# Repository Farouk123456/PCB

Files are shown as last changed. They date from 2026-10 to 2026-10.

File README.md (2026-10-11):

# Submission for Halflife's Week 1 PCB design

## CPULess Multiplexed LED Matrix 

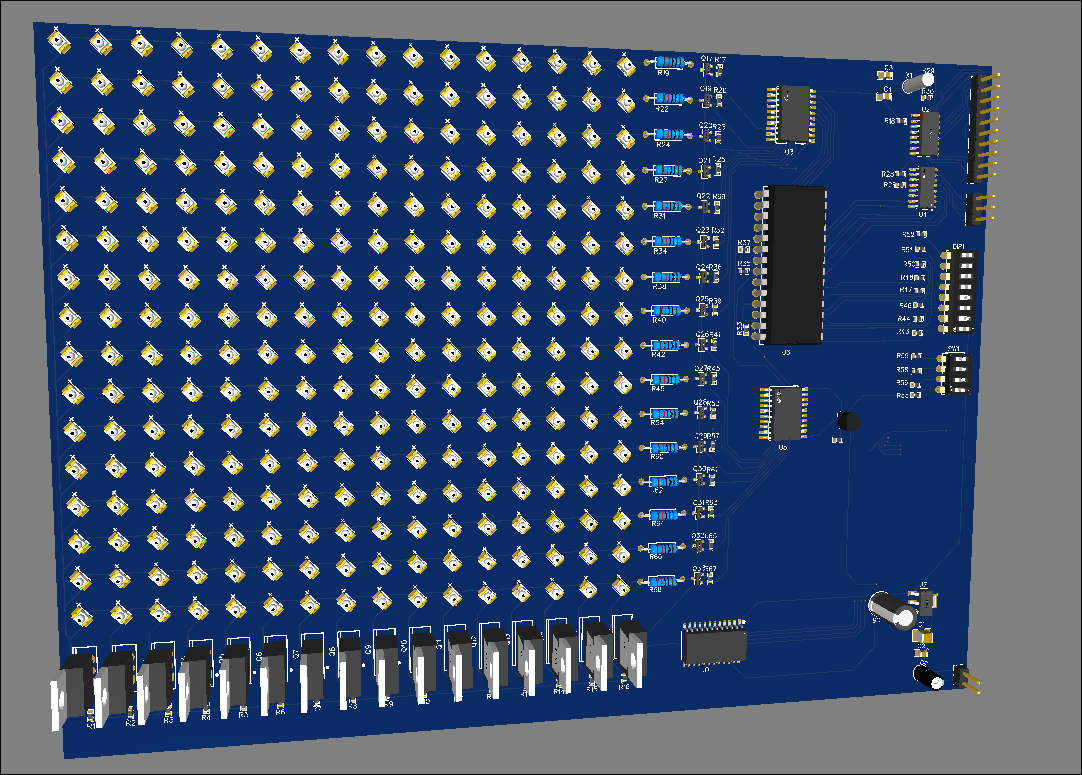
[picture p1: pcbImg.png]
PCB Model Image


This is a 16x16 LED display/matrix that's driven only by logic gates and an AT28C256 EEPROM to store an image, meaning there's no CPU or microcontroller that's controlling the LEDs.

I was motivated to make this to challenge myself to see what it would take and if I could actually design something complex that works, hopefully!

When the board powers on, a crystal oscillator is used alongside a 74HC4060 IC counter to generate a clock signal and to (in the future) automatically cycle between images using the counter that is its intended purpose.

That clock signal powers a 74HC590 8-bit counter that sets which row (or column, depending on how you want to look at it) is now to be displayed
A 74HC4514 demultiplexer IC actually enforces what the counter sets and powers on one row at a time (the multiplexing part). 

Simultaneously the counter value gets passed to the EEPROM as an address.
The EEPROM then returns the values of half a column of LEDs as an 8-bit value.
The value travels through one of two buffer ICs and through some transistors to power on the selected LEDs.

On the next clock cycle the other half is displayed by the EEPROM

Then a new row is addressed until it reaches row 16, where the counter resets and the process happens all over again

The 12 DIP switches allow me to select one of 4096 possible images to be displayed on the matrix
(It's noteworthy to say that my implementation only allows the LEDs to be either on or off.)

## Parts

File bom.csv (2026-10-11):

Index | LCSC# | MPN | Manufacturer | Package | Customer # | Description | RoHS | Quantity | MOQ | Multiple | Unit Price($) | Extended Price($) | Product Link
1 | C3356784 | MFR-12FTF52-10K | YAGEO | Through Hole,D1.9xL3.4mm |  | 10kΩ 167mW Metal Film Resistor ±100ppm/℃ ±1% Through Hole,D1.9xL3.4mm Through Hole Resistors RoHS | yes | 100 | 50 | 50 | 0.0113 | 1.13 | https://www.lcsc.com/product-detail/C3356784.html
2 | C52121519 | HG74HC595N | HGSEMI | DIP-16 |  | 3.2V~5.5V 35mA 100ns@5V,50pF Serial-to-Parallel DIP-16 Shift Registers | yes | 5 | 5 | 5 | 0.1336 | 0.67 | https://www.lcsc.com/product-detail/C52121519.html
3 | C907564 | CD02K032768ACNBAEAE | TKD | DT-38 |  | 12.5pF ±10ppm DT-38 Crystals | yes | 10 | 10 | 10 | 0.0602 | 0.60 | https://www.lcsc.com/product-detail/C907564.html
4 | C544820 | LM3940IMPX-3.3/NOPB | TI | SOT-223-4 |  | Linear Voltage Regulator IC Positive Fixed 1 Output 1A SOT-223-4 | yes | 1 | 1 | 1 | 1.5028 | 1.50 | https://www.lcsc.com/product-detail/C544820.html
5 | C1348752 | AT28C256-15PU | MICROCHIP | PDIP-28 |  | 256Kbit Parallel Port (Parallel) PDIP-28 Memory RoHS | yes | 1 | 1 | 1 | 19.4572 | 19.46 | https://www.lcsc.com/product-detail/C1348752.html
6 | C2652997 | SN74HC590ADR | TI | SOIC-16 |  | Rising Edge 1 24MHz SOIC-16 Counters, Dividers RoHS | yes | 1 | 1 | 1 | 0.8522 | 0.85 | https://www.lcsc.com/product-detail/C2652997.html
7 | C548810 | 74LVC541AD-Q100J | Nexperia | SO-20-300mil |  | Schmitt trigger 1.65V~3.6V 8 1 2.9ns@3.3V,50pF SO-20-300mil Buffers, Drivers, Receivers, Transceivers RoHS | yes | 2 | 1 | 1 | 1.0705 | 2.14 | https://www.lcsc.com/product-detail/C548810.html
8 | C134017 | CD74HC4060M96 | TI | SOIC-16 |  | Falling Edge 1 35MHz SOIC-16 Counters, Dividers RoHS | yes | 1 | 1 | 1 | 0.4685 | 0.47 | https://www.lcsc.com/product-detail/C134017.html
9 | C50202050 | XL74HC4514D | XINLUDA | SOP-24 |  | 4/16 2V~6V 80uA 49ns@6.0V,50pF SOP-24 Signal Switches, Multiplexers, Decoders | yes | 5 | 5 | 5 | 0.3097 | 1.55 | https://www.lcsc.com/product-detail/C50202050.html
10 | C99987 | EI-04 | Diptronics | Through Hole,P=2.54mm |  | Dip Switch SPST 4 Position Slide, Rocked | yes | 1 | 1 | 1 | 0.5224 | 0.52 | https://www.lcsc.com/product-detail/C99987.html
11 | C20611863 | MF0204FTE52-2K2 | YAGEO | Through Hole,D1.9xL3.4mm |  | 2.2kΩ 400mW Metal Film Resistor ±50ppm/℃ ±1% Through Hole,D1.9xL3.4mm Through Hole Resistors | yes | 50 | 50 | 50 | 0.0115 | 0.58 | https://www.lcsc.com/product-detail/C20611863.html
12 | C3000673 | FRC2512F1004TS | FOJAN | 2512 |  | 1MΩ ±1% 1W 2512 Thick Film Resistor | yes | 20 | 20 | 20 | 0.0324 | 0.65 | https://www.lcsc.com/product-detail/C3000673.html
13 | C119285 | MF1/4W-15Ω±1% T | CCO(Chian Chia Elec) | Through Hole,D2.3xL6.5mm |  | 15Ω 250mW 250V Metal Film Resistor ±100ppm/℃ ±1% Through Hole,D2.3xL6.5mm Through Hole Resistors RoHS | yes | 50 | 50 | 50 | 0.0109 | 0.55 | https://www.lcsc.com/product-detail/C119285.html
14 | C49270298 | CSA0805C0G103J500MT | HRE | 0805 |  | 10nF C0G ±5% 50V 0805 Ceramic Capacitors | yes | 20 | 20 | 20 | 0.0312 | 0.62 | https://www.lcsc.com/product-detail/C49270298.html
15 | C2910414 | 2N7000-TA | JSCJ | TO-92 |  | N-Channel 60V 0.2A 0.625W Through Hole TO-92 | yes | 20 | 20 | 20 | 0.0451 | 0.90 | https://www.lcsc.com/product-detail/C2910414.html
16 | C21713833 | AO3401CI-ES | ElecSuper | SOT-23 |  | P-Channel 20V 2.3A 1.4W Surface Mount SOT-23 | yes | 50 | 50 | 50 | 0.0191 | 0.96 | https://www.lcsc.com/product-detail/C21713833.html
17 | C54839582 | IRLZ44NPBF-MNS | Minos | TO-220 |  | 100W 60V 50A 15mΩ@10V 1 N-channel N-Channel TO-220 Single FETs, MOSFETs | yes | 20 | 5 | 5 | 0.3046 | 6.09 | https://www.lcsc.com/product-detail/C54839582.html
18 | C131211 | 42-21A/GHC-YX1Y2N/1T | EVERLIGHT | SMD,3.2x2.4mm |  | Emerald Green 518nm LED Indication - Discrete SMD,2.4x3.2mm | yes | 260 | 10 | 10 | 0.0501 | 13.03 | https://www.lcsc.com/product-detail/C131211.html
19 | C124375 | B-2100S02P-A110 | Ckmtw | Through Hole,P=2.54mm |  | Pin Header 2 Position 2.54mm Pitch Single Row Through Hole -40℃~+105℃ | yes | 20 | 20 | 20 | 0.0300 | 0.60 | https://www.lcsc.com/product-detail/C124375.html
20 | C54557117 | 5557WRF-1X3P(HDGC4201WR-F-1X3P) | HDGC | Through Hole,Right Angle,P=4.2mm |  | Right Angle 600V 3 1 4.2mm 9A 3P -25℃~+85℃ Tin 1x3P Through Hole,Right Angle,P=4.2mm Headers, Male Pins RoHS | yes | 5 | 5 | 5 | 0.1759 | 0.88 | https://www.lcsc.com/product-detail/C54557117.html
21 | C42391526 | HX PZ-2005WV-1x10P | hanxia | Through Hole,P=2mm |  | Through Hole 500V 1 2mm 1.5A Square pin 2mm 3.9mm 10P -40℃~+105℃ Gold 2.8mm Black 1x10P Through Hole,P=2mm Headers, Male Pins RoHS | yes | 10 | 10 | 10 | 0.0492 | 0.49 | https://www.lcsc.com/product-detail/C42391526.html
22 | C90019 | EI-08-V | Diptronics | Through Hole,P=2.54mm |  | 8 25mA Black SPST 2,000 cycles Slide, Rocked Through Hole,P=2.54mm DIP Switches RoHS | yes | 1 | 1 | 1 | 0.8551 | 0.86 | https://www.lcsc.com/product-detail/C90019.html
23 | C216549 | ECR1HPT330MLL063011 | Nantong Jianghai Capacitor | Through Hole,D6.3xL11.5mm |  | 33uF 50V Aluminum Electrolytic Capacitors Through Hole,D6.3xL11.5mm 2000hrs@85℃ | yes | 20 | 20 | 20 | 0.0277 | 0.55 | https://www.lcsc.com/product-detail/C216549.html
24 | C45095 | kF474M050C05RR0VH2FP0 | Chengx | Through Hole,D4xL5mm |  | ±20% 50V 470nF Through Hole,D4xL5mm Aluminum Electrolytic Capacitors RoHS | yes | 50 | 50 | 50 | 0.0096 | 0.48 | https://www.lcsc.com/product-detail/C45095.html
25 | C3838790 | 600F330JT250XT | Kyocera AVX | 0805 |  | 33pF C0G ±5% 250V 0805 Ceramic Capacitors RoHS | yes | 2 | 1 | 1 | 0.2620 | 0.52 | https://www.lcsc.com/product-detail/C3838790.html

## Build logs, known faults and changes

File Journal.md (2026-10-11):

7 October

1 AM: Just got back from a student party; let's get to work.

3:20 AM: Made a schematic for the LED matrix and column multiplexer; still have to figure out how to address the rows and how to give the LEDs values that create nice patterns

8 October

In this session, I actually figured out how I wanted this matrix to work, which is using an EEPROM that stores arbitrary images that you can switch to using dip switches
I had to get creative to make it work since a row of the 16x16 matrix doesn't fit cleanly into the 8 bits that get stored per address on the EEPROM, so I had to split the display in half using 2 buffer ICs and display only one half each clock cycle

I needed 2 binary counter ICs, one to make the crystal clock, as it seems like a clean way to accomplish that because it leaves signals for future control, like if I wanted to make the images switch automatically, I could use the unused 1 Hz and bigger signals to address the eeprom!

9 October

Designed the PCB and added a voltage regulator to turn 5V into 3.3V and made sure the traces could handle the current of the LEDs.
The only thing left is to write some code to program the EEPROM/example image dump of an EEPROM, and maybe if I figure it out, simulate the PCB to find errors that I've missed

9 October After Sleeping: Disaster

Realized I hadn't checked the current of the LEDs I used (they were too high) -> had to replace all LEDs and transistors because their current rating was wrong, meaning all the work I did yesterday was useless, and I have to do it all over again. This time I'm going to meticulously check each component for such things as my LEDs might need resistors now.

Added 15 ohm resistors per row because (3.3V - 3V) / 0.02 = 15 Ohm

Designed almost 50% of the PCB and made 15h reel

10 October 

Finished PCB wiring had to relocate the regulator region to make routing easier
Realized (using AI) that 74HC154 inverts the signal of the demultiplexers, so I need to use something else. 
Found some routing mistakes and swaps
Also, AI pointed out that my 15-ohm resistor placement is wrong and that the buffer IC can't directly drive the LEDs, so I'll also need to fix that
Fixed it now. I hope I'm done with the hard work. What's left is to write a program to return an image to be uploaded to the EEPROM using an Arduino or a programmer

Actually, AI found that I reversed the polarity of a capacitor and that I need to use pull-up resistors for my p-channel MOSFETs because controlling the output using the enable pin allows the gate to be floating, but I'm not sure there shouldn't be any more issues

Need 2 74HC595 to programm EEPROM with what i have

My outline for the programmer App:

Python scans folder for numbered BMP images gray scales them and then sets bit value based on brightness to on or off and Dumps a output.bin file to be programmed onto the EEPROM

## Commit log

2026-10-07 Day 2 for me finished rev 1 of schematic
    [Sheet_1_2026-10-07.schdoc]
2026-10-08 added regulator
    [BOM_LED-Matrix-Halflife_2026-10-08.csv, Sheet_1_2026-10-08.schdoc]
2026-10-09 day 3 end
    [BOM.csv, BOM_LED-Matrix-Halflife_2026-10-08.csv, Schematic.schdoc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]
2026-10-09 trying to fix bom
    [BOM.csv]
2026-10-10 day 3.2
    [BOM.csv, Schematic.schdoc, schematic.schdoc]
2026-10-11 day 4
    [BOM.csv, schematic.schdoc]
2026-10-11 bom update moq
    [BOM.csv]
2026-10-11 acctual cart
    [BOM.csv, export_cart_20261011_115742.csv]
